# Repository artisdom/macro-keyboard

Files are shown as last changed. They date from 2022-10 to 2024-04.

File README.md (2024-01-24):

# Macro Keyboard

A Macro keyboard built on ESP32-S3.    

## Features

- Layouts: QMK style
- Macros: fakes multiple key presses on a single key.
- Deep sleep
- Battery level reports
- HID over USB or BLE.
- Support for multiple BLE hosts and specific key layout to switch between them.
- LED backlight with brightness control + effects for BLE actions

## Requirements

### Firmware

Using esp-idf (master branch)

### Hardware

Using Kicad v6.0

## Build

See the esp-idf [instructions](https://docs.espressif.com/projects/esp-idf/en/latest/esp32s3/get-started/index.html) on getting started.

To build:

```shell
idf.py build
```

To flash:

```shell
idf.py flash [-p port_name]
```

To get a console:

```shell
idf.py monitor [-p port_name]
```

### Keyboard Configuration

Each keyboard is defined in it's own subdirectory in the [keyboards](./firmware/keyboards) directory.
This keyboards directory is actually registered as a esp-idf component and will be built as a library and then linked with the [main](./firmware/main) component.

To choose which keyboard to compile for:

```shell
idf.py menuconfig
```
then `Keyboard Configuration` > `Keyboard to build`: Enter the name of the subdirectory for your keyboard.

## Todo

- Cleanup BLE files.
- Create an HID level to create packets to be routed to BLE or USB later on (waiting on esp to finish their esp_hid component).
- QMK features:
	- Make keymap fully compatible with QMK (maybe use the [QMK configurator](https://github.com/qmk/qmk_configurator) or the web api to compile keymaps).
	- Support for more Layer modifiers (one-shot, tap, etc...).
    - Better VIA compatibility (even thought it's a custom fork).
- Better NVS stuff (layouts, configs, ...etc).
- Better Battery reports (when init ble connection use read level).
- Low Battery management: indicator + shutdown.
- Battery optimisations: reduce polling rate when on battery + light sleep + power profiling for leakage currents.
- Clean up HID descriptors to make them common between USB and BLE stacks.
- Better USB deinit (waiting on TinyUSB implementation).
- USB CDC and HID device in parallel to get log outputs in serial port.
- MIDI device?
- Mutiple BLE hosts in parallel? + BLE 5 features?
- If design is kept as BLE only, shift implementation to NimBLE stack (not Bluedroid).
- SPI RAM usage? disabled for now because it was making boot time far too long.

## Issues

- Potential issue when switching BLE host: the hid report array is not propably reset.  
Should not be an issue as BLE host changes are supposed to happen without other keys being pressed.
- BLE local name needs to be less than 15 characters. Otherwise macOS will not show it in the discovery menu.

## License

Firmware and Software: MIT

Hardware: CERN-OHL-W v2

## Docs / Referencs

- ESP-IDF [Guide](https://docs.espressif.com/projects/esp-idf/en/v4.4.2/esp32s3/index.html).
- ESP32-S3 [Datasheet](https://www.espressif.com/sites/default/files/documentation/esp32-s3_datasheet_en.pdf).
- ESP32-S3 [Technical Reference Manual](https://www.espressif.com/sites/default/files/documentation/esp32-s3_technical_reference_manual_en.pdf).
- [TinyS3](https://esp32s3.com/index.html#home) board.
- [Blog](http://blog.komar.be/how-to-make-a-keyboard-the-matrix/) on matrix keyboard design. 
- QMK [keymaps](https://docs.qmk.fm/#/keymap?id=keymap-and-layers) and [layers](https://docs.qmk.fm/#/feature_layers) documentation.
- USB HID [usage tables](https://www.usb.org/sites/default/files/hut1_4.pdf)

### Inspirations

- [QMK](https://github.com/qmk/qmk_firmware/) for AVR devices.
- [MK32](https://github.com/Galzai/MK32) a QMK style firmware for ESP32 devices.

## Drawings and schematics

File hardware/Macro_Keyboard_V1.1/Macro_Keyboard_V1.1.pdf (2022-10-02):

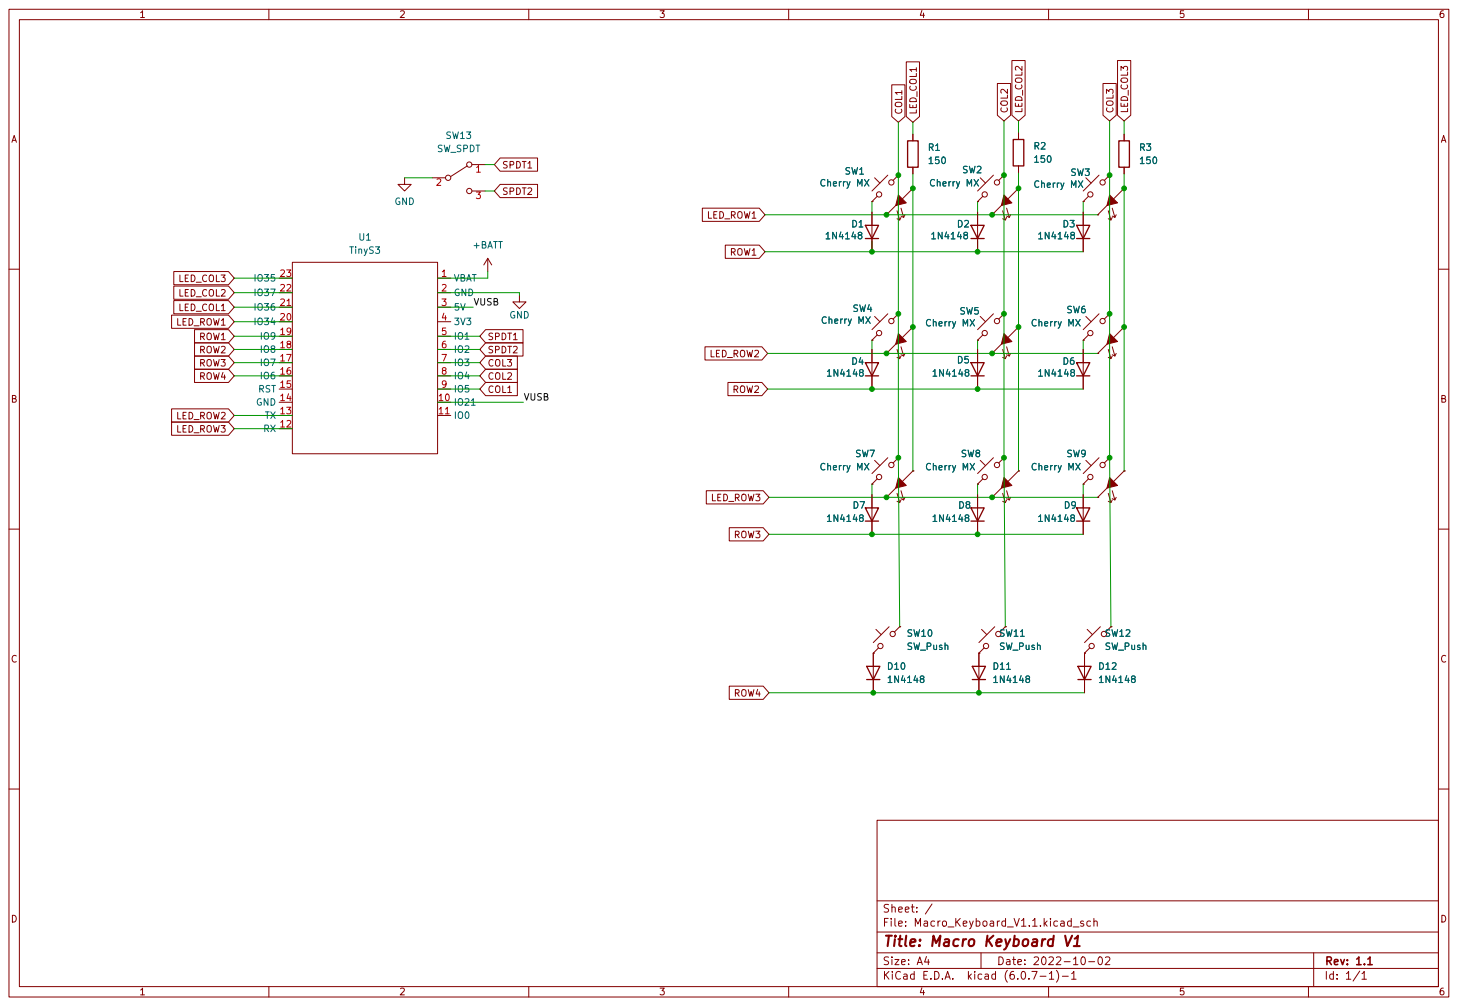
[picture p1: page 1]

File: Macro_Keyboard_V1.1.kicad_sch Sheet: /
Id: 1/1 Title: Macro Keyboard V1

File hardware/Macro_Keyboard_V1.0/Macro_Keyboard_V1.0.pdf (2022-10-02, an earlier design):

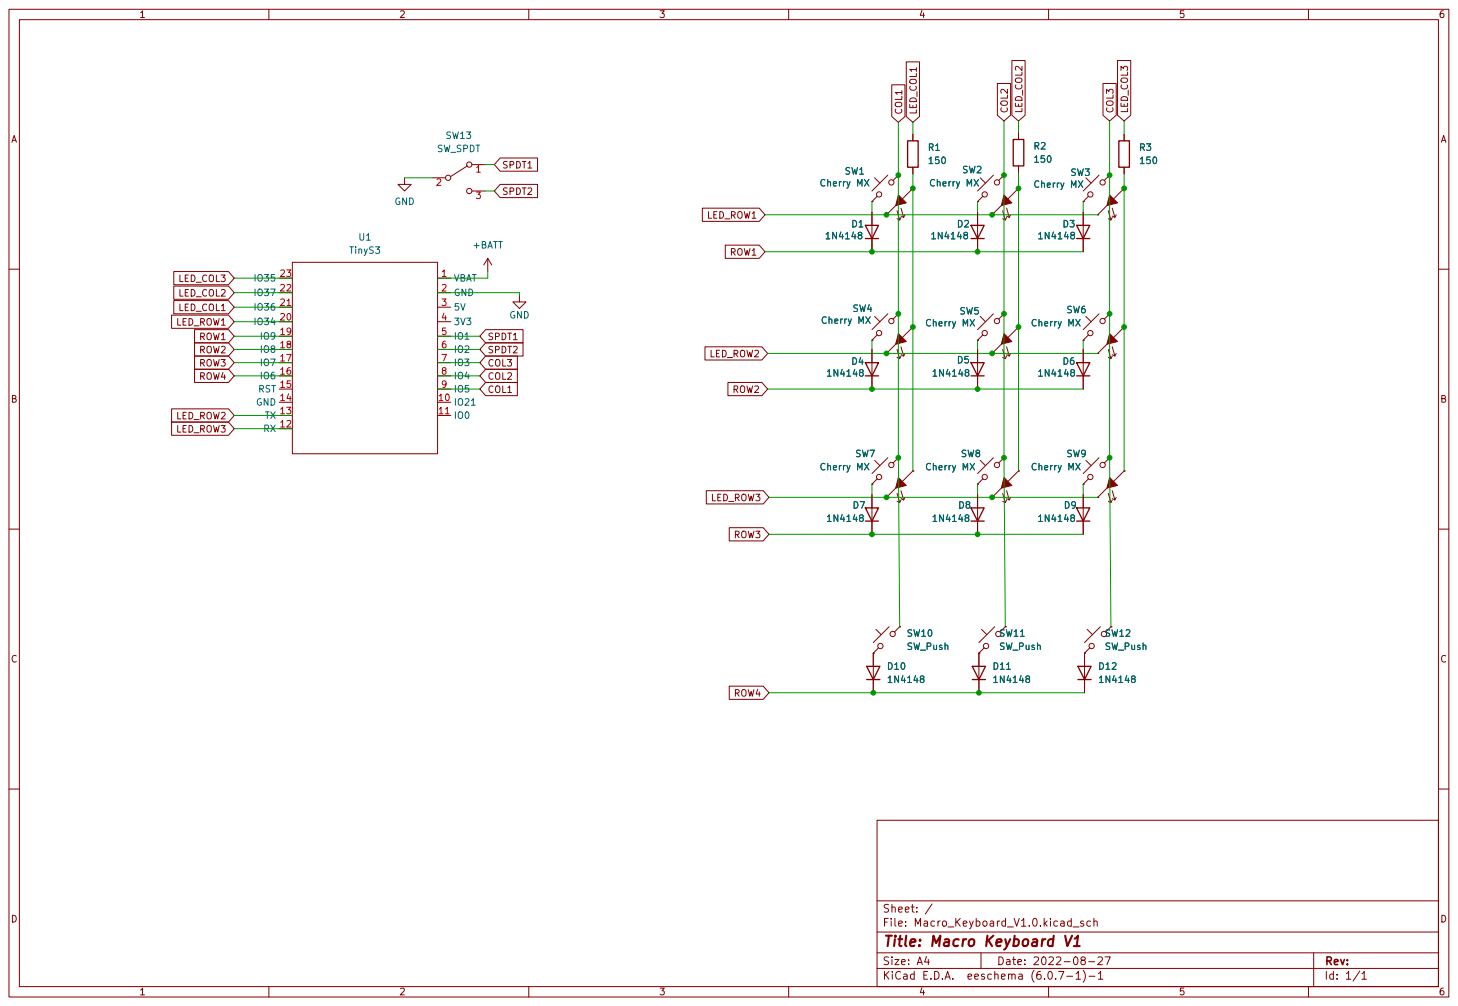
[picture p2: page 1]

File: Macro_Keyboard_V1.0.kicad_sch Sheet: /
Id: 1/1 Title: Macro Keyboard V1

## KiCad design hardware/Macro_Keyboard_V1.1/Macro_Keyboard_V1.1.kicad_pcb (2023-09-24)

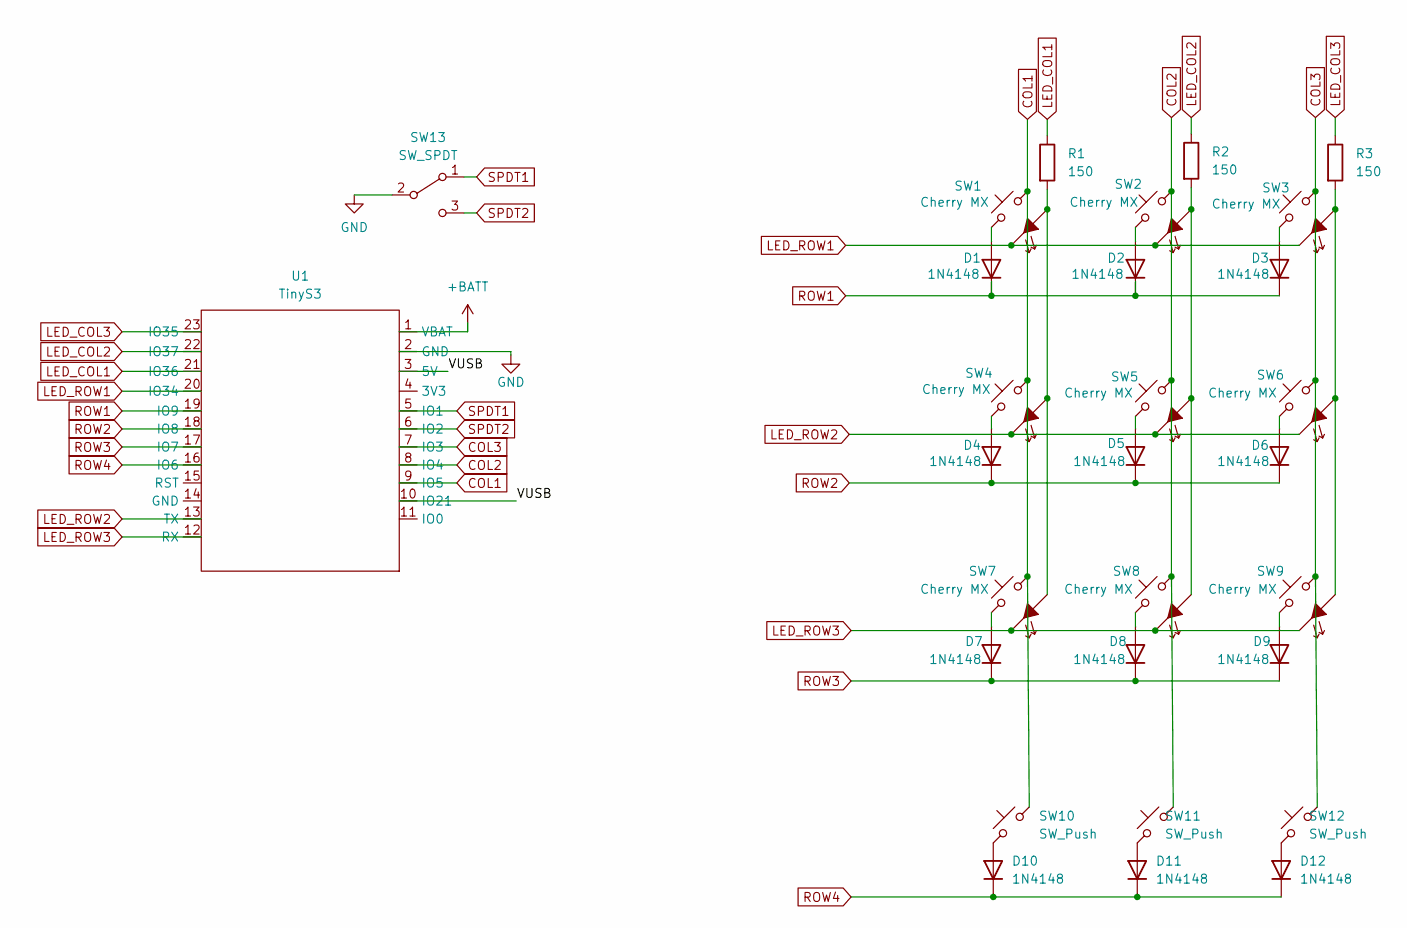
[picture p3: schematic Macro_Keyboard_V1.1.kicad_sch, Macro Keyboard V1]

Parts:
D1, D2, D3, D4, D5, D6, D7, D8, D9, D10, D11, D12: 1N4148; D_SOD-123
R1, R2, R3: 150; R_1206_3216Metric_Pad1.30x1.75mm_HandSolder
SW1, SW2, SW3, SW4, SW5, SW6, SW7, SW8, SW9: Cherry MX; CherryMX_1.00u_LED
SW10, SW11, SW12: SW_Push; SW_PUSH_6mm_H7.3mm
SW13: SW_SPDT; SK12D07VG4
U1: TinyS3

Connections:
+BATT: U1.1 (VBAT); also elsewhere on the board
/VUSB: U1.3 (5V), U1.10 (IO21)
COL1: SW1.1, SW4.1, SW7.1, SW10.2, U1.9 (IO5)
COL2: SW2.1, SW5.1, SW8.1, SW11.2, U1.8 (IO4)
COL3: SW3.1, SW6.1, SW9.1, SW12.2, U1.7 (IO3)
GND: SW13.2 (B), U1.2 (GND); also elsewhere on the board
LED_COL1: R1.1, U1.21 (IO36)
LED_COL2: R2.1, U1.22 (IO37)
LED_COL3: R3.1, U1.23 (IO35)
LED_ROW1: SW1.4, SW2.4, SW3.4, U1.20 (IO34)
LED_ROW2: SW4.4, SW5.4, SW6.4, U1.13 (TX)
LED_ROW3: SW7.4, SW8.4, SW9.4, U1.12 (RX)
unnamed: D1.2 (A), SW1.2
unnamed: D2.2 (A), SW2.2
unnamed: D3.2 (A), SW3.2
unnamed: D4.2 (A), SW4.2
unnamed: D5.2 (A), SW5.2
unnamed: D6.2 (A), SW6.2
unnamed: D7.2 (A), SW7.2
unnamed: D8.2 (A), SW8.2
unnamed: D9.2 (A), SW9.2
unnamed: D10.2 (A), SW10.1
unnamed: D11.2 (A), SW11.1
unnamed: D12.2 (A), SW12.1
unnamed: R1.2, SW1.3, SW4.3, SW7.3
unnamed: R2.2, SW2.3, SW5.3, SW8.3
unnamed: R3.2, SW3.3, SW6.3, SW9.3
ROW1: D1.1 (K), D2.1 (K), D3.1 (K), U1.19 (IO9)
ROW2: D4.1 (K), D5.1 (K), D6.1 (K), U1.18 (IO8)
ROW3: D7.1 (K), D8.1 (K), D9.1 (K), U1.17 (IO7)
ROW4: D10.1 (K), D11.1 (K), D12.1 (K), U1.16 (IO6)
SPDT1: SW13.1 (A), U1.5 (IO1)
SPDT2: SW13.3 (C), U1.6 (IO2)

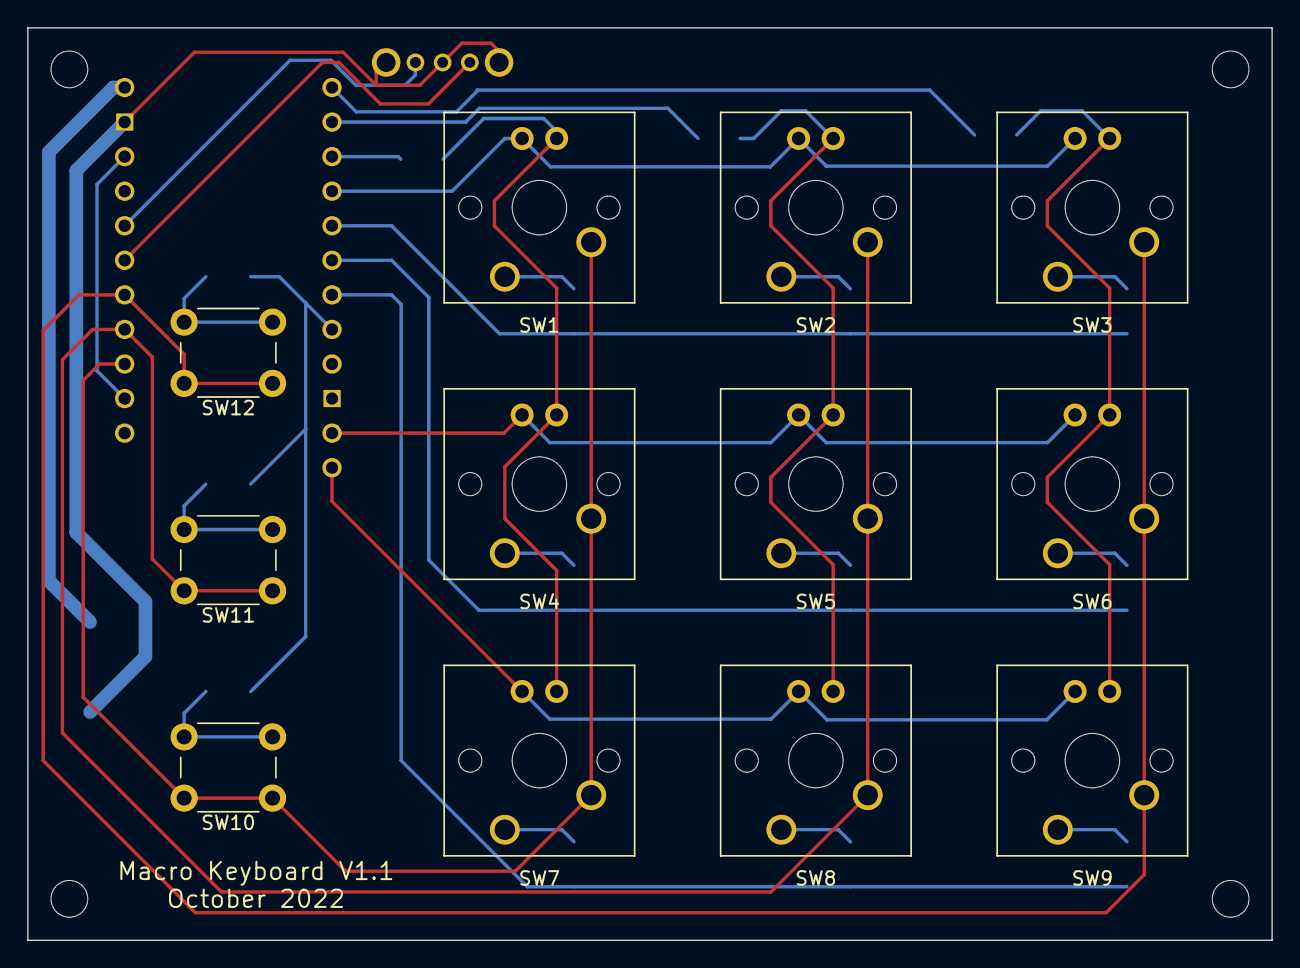
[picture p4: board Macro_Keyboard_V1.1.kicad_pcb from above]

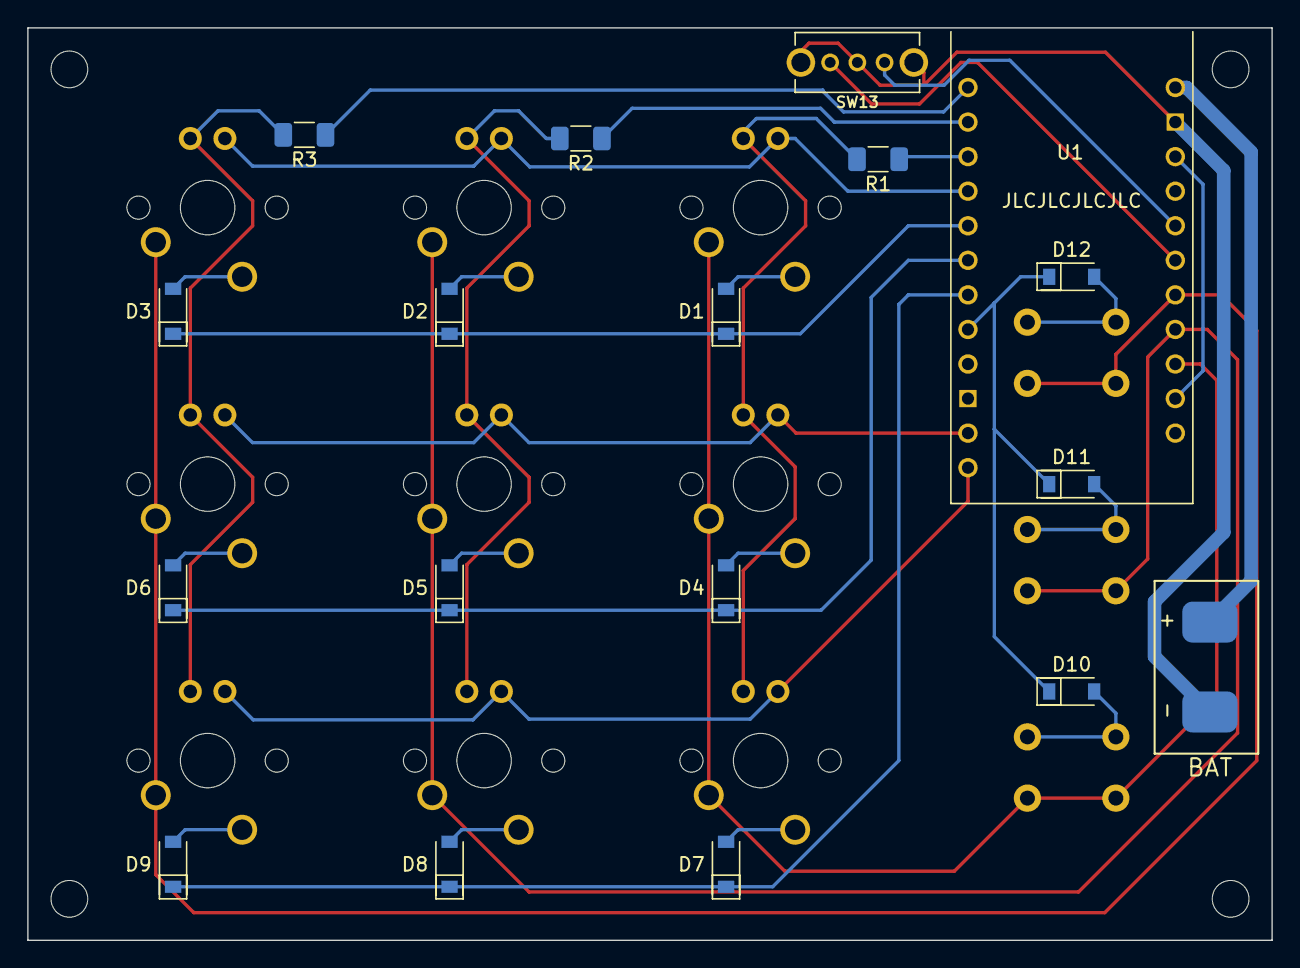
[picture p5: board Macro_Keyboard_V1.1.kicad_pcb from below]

Board: 2 copper layers, 91.4 x 67.1 mm, 31 parts (19 on the bottom side), 33 nets.

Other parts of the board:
+: SolderWirePad_1x01_SMD_3x4mm
-: SolderWirePad_1x01_SMD_3x4mm

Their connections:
+BATT: +.1; also elsewhere on the board
GND: -.1; also elsewhere on the board

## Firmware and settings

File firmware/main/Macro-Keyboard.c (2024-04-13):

#define LOG_LOCAL_LEVEL     ESP_LOG_DEBUG

#include <string.h>
#include "freertos/FreeRTOS.h"
#include "freertos/task.h"
#include "freertos/queue.h"
#include "esp_event.h"
#include "esp_sleep.h"
#include "esp_timer.h"
#include "esp_log.h"
#include "esp_system.h"
#include "driver/uart.h"
#include "driver/gpio.h"

#include "matrix.h"
#include "keyboard.h"
#include "memory.h"
#include "leds.h"
#include "events.h"
#include "toggle_switch.h"
#include "battery.h"
#include "ble.h"
#include "usb.h"


/* --------- Global Variables --------- */
QueueHandle_t event_q;
QueueHandle_t media_q;


/* --------- Local Defines --------- */
#define USEC_TO_SEC 1000000
#define SEC_TO_MIN 60

#define DEEP_SLEEP_TASK_RATE (5000) //in ms
#define BATTERY_TASK_RATE (DEEP_SLEEP_TIMEOUT * 1000 / 2)  //in ms


/* --------- Local Variables --------- */
static const char *TAG = "main";

static bool DEEP_SLEEP = true;

static uint8_t mode = TOGGLE_BLE;
static bool usb_connected;


/* --------- Local Functons --------- */
static void sleep(bool rtc_keyboard, bool rtc_toggle_switch, bool rtc_usb, bool rtc_usb_direction);
static void restart(restart_type_t type);


void keyboard_task(void *parameters) {

    uint8_t past_report[HID_REPORT_LEN] = {0};
    uint8_t *current_report;

    ESP_LOGI(TAG, "Starting keyboard task");

    while(1) {
        current_report = keyboard__check_state();

        // only send report if it changed
        if (memcmp(past_report, current_report, sizeof(past_report)) != 0) {
            DEEP_SLEEP = false;

            memcpy(past_report, current_report, sizeof(past_report));

            ESP_LOGD(TAG, "HID report:  0x%x,0x%x,  0x%x,0x%x,0x%x,0x%x,0x%x,0x%x",
                current_report[0], current_report[1], current_report[2], current_report[3],
                current_report[4], current_report[5], current_report[6], current_report[7]);

            if (BLE_ENABLED && (mode == TOGGLE_BLE)) {
                xQueueSend(ble_keyboard_q, (void *) current_report, (TickType_t) 0);
            }
            if (USB_ENABLED && (mode == TOGGLE_USB)) {
                xQueueSend(usb_keyboard_q, (void *) current_report, (TickType_t) 0);
            }

        }

        if (usb_connected == true) {
            vTaskDelay(KEYBOARD_RATE / portTICK_PERIOD_MS);
        }
        else {
            vTaskDelay(KEYBOARD_BLE_RATE / portTICK_PERIOD_MS);
        }
    }
    vTaskDelete(NULL);
    
}


void media_task(void *pvParameters) {

    uint8_t report[HID_CC_REPORT_LEN];
    uint8_t past_report[HID_CC_REPORT_LEN];

    ESP_LOGI(TAG, "Starting media task");

    while(1) {

        if (xQueueReceive(media_q, &report, (TickType_t) 100)) {
            // only send report if it changed
            if(memcmp(past_report, report, sizeof(past_report)) != 0) {
                DEEP_SLEEP = false;
                memcpy(past_report, report, sizeof(past_report));

                ESP_LOGD(TAG, "HID CC report:  %d,%d", report[0], report[1]);

                if (BLE_ENABLED && (mode == TOGGLE_BLE)) {
                    xQueueSend(ble_media_q, (void *) report, (TickType_t) 0);
                }
                if (USB_ENABLED && (mode == TOGGLE_USB)) {
                    xQueueSend(usb_media_q, (void *) report, (TickType_t) 0);
                }

            }    
        }

        if (usb_connected == true) {
            vTaskDelay(KEYBOARD_RATE / portTICK_PERIOD_MS);
        }
        else {
            vTaskDelay(KEYBOARD_BLE_RATE / portTICK_PERIOD_MS);
        }
    }
    vTaskDelete(NULL);

}


void battery_task(void *pvParameters) {

    ESP_LOGI(TAG, "Starting battery task");

    while(1) {
        uint32_t battery_level = battery__get_level();

        if (battery__is_charging()) {
            // if charging, disable DEEP_SLEEP
            DEEP_SLEEP = false;
        }

        if (BLE_ENABLED && (mode == TOGGLE_BLE)) {
            xQueueSend(ble_battery_q, &battery_level, (TickType_t) 0);
        }

        vTaskDelay(BATTERY_TASK_RATE / portTICK_PERIOD_MS);
    }

}


void deep_sleep_task(void *pvParameters) {
    uint64_t initial_time = esp_timer_get_time(); // time in micro-seconds
    uint64_t current_time_passed = 0;

    ESP_LOGI(TAG, "Starting deep sleep task");

    while (1) {
        current_time_passed = (esp_timer_get_time() - initial_time);

        if (DEEP_SLEEP == false) {
            current_time_passed = 0;
            initial_time = esp_timer_get_time();
            DEEP_SLEEP = true;
        }

        if (((double)current_time_passed/USEC_TO_SEC) >= (double)(DEEP_SLEEP_TIMEOUT)) {
            if (DEEP_SLEEP == true) {
                ESP_LOGW(TAG, "Deep sleep triggered");

                // deinits
                if (BLE_ENABLED && (mode == TOGGLE_BLE) && (ble__deinit() != ESP_OK)) {
                    ESP_LOGE(TAG, "Unable to go to sleep!");
                    DEEP_SLEEP = false;
                    continue;                    
                }
                if (USB_ENABLED && (mode == TOGGLE_USB) && (usb__deinit() != ESP_OK)) {
                    ESP_LOGE(TAG, "Unable to go to sleep!");
                    DEEP_SLEEP = false;
                    continue;                    
                }

                sleep(true, false, false, 0);
            }
            if (DEEP_SLEEP == false) {
                current_time_passed = 0;
                initial_time = esp_timer_get_time();
                DEEP_SLEEP = true;
            }
        }
        vTaskDelay(DEEP_SLEEP_TASK_RATE / portTICK_PERIOD_MS);
    }
    vTaskDelete(NULL);

}


void event_handler_task(void *parameters) {

    bt_event_t bt_event;

    ESP_LOGI(TAG, "Starting event handler task");

    if (event_q == NULL) {
        ESP_LOGW(TAG, "event queue not initialised, resetting...");
        xQueueReset(event_q);
    }

    while(1) {
        event_t event;
        event_t new_event;
        memset(&event, 0x00, sizeof(event_t));

        if(xQueueReceive(event_q, &event, portMAX_DELAY)) {
            
            switch(event.type) {
                case EVENT_KB_CHANGE_BT_HOST: {
                    bt_event.type = BT_EVENT_CHANGE_HOST;
                    bt_event.host_id = event.data;

                    if (BLE_ENABLED && (mode == TOGGLE_BLE)) {
                        ESP_LOGI(TAG, "Changing BLE device to %d", event.data);
                        xQueueSend(ble_event_q, &bt_event, (TickType_t) 0);
                    }
                    break;
                }
                case EVENT_KB_RESET_BT_HOST: {
                    bt_event.type = BT_EVENT_RESET_HOST;
                    bt_event.host_id = event.data;

                    if (BLE_ENABLED && (mode == TOGGLE_BLE)) {
                        ESP_LOGI(TAG, "Resetting BLE device at %d", event.data);
                        xQueueSend(ble_event_q, &bt_event, (TickType_t) 0);
                    }
                    break;
                }
                case EVENT_TOGGLE_SWITCH: {
                    if ((event.data == TOGGLE_BLE)) {
                        // ESP_LOGW(TAG, "event toggle ble");
                        if (USB_ENABLED) {
                            usb__deinit();
                        }
                        if (BLE_ENABLED) {
                            ESP_LOGI(TAG, "Toggle BLE");
                            if (LED_ENABLED && LED_EFFECTS_ENABLED) {
                                new_event.type = EVENT_BT_LEDS_EFFECT_TOGGLE,
                                new_event.data = true;
                                xQueueSend(leds_q, &new_event, (TickType_t) 0);
                            }
                            mode = event.data;
                            ble__init();
                        }
                    }
                    else if ((event.data == TOGGLE_USB)) {
                        // ESP_LOGW(TAG, "event toggle usb");
                        usb_connected = usb__is_connected();
                        if (BLE_ENABLED) {
                            if (LED_ENABLED && LED_EFFECTS_ENABLED) {
                                new_event.type = EVENT_BT_LEDS_EFFECT_TOGGLE,
                                new_event.data = false;
                                xQueueSend(leds_q, &new_event, (TickType_t) 0);
                            }
                            ble__deinit();
                        }
                        if (USB_ENABLED) {
                            if (usb_connected) {
                                ESP_LOGI(TAG, "Toggle USB");
                                mode = event.data;
                                usb__init();
                            }
                            else {
                                sleep(false, true, true, !usb_connected);
                            }
                        }
                        else {
                            sleep(false, true, false, 0);
                        }
                    }
                    else {
                        ESP_LOGW(TAG, "Unknown toggle event type %d", event.data);
                    }
                    break;
                }
                case EVENT_KB_LEDS: {
                    if (LED_ENABLED) {
                        switch (event.data) {
                            case LEDS_ON:
                                ESP_LOGD(TAG, "Leds on");
                                leds__enable_backlight(true);
                                break;
                            case LEDS_OFF:
                                ESP_LOGD(TAG, "Leds off");
                                leds__enable_backlight(false);
                                break;
                            case LEDS_TOGGLE:
                                ESP_LOGD(TAG, "Leds toggle");
                                leds__toggle_backlight();
                                break;
                            case LEDS_INCREMENT:
                                ESP_LOGD(TAG, "Leds increase brightness");
                                leds__increase_brightness();
                                break;
                            case LEDS_DECREMENT:
                                ESP_LOGD(TAG, "Leds decrease brightness");
                                leds__decrease_brightness();
                                break;
                            default:
                                ESP_LOGE(TAG, "Unrecognised KB_LEDS event data %d", event.data);
                                break;
                        }
                    }
                    break;
                }
                case EVENT_BT_ADV:
                case EVENT_BT_ADV_ALL:
                case EVENT_BT_CONNECTED:
                case EVENT_LAYERS_CHANGED: {
                    if (LED_ENABLED && LED_BT_EFFECTS_ENABLED) {
                        ESP_LOGI(TAG, "Leds FX event, host: %d", event.data);
                        xQueueSend(leds_q, &event, (TickType_t) 0);
                    }
                    break;
                }
                case EVENT_USB_PORT: {
                    vTaskDelay(1 / portTICK_PERIOD_MS); // delay to wait for voltage to stabilise on pin
                    usb_connected = usb__is_connected();
                    if (usb_connected == true) {
                        ESP_LOGI(TAG, "USB Connected");
                    }
                    else {
                        ESP_LOGI(TAG, "USB Disconnected");
                        if (mode == TOGGLE_USB) {
                            sleep(false, true, true, 1);
                        }

                    }
                    break;
                }
                case EVENT_RESTART: {
                    if (event.data > 0) {
                        restart((restart_type_t) event.data);
                    }
                    else {
                        ESP_LOGE(TAG, "Unrecognised EVENT_RESTART event data %d", event.data);
                    }
                    break;
                }
                default:
                    ESP_LOGW(TAG, "Unhandled event type");
                    break;
            }
        }
    }
    vTaskDelete(NULL);
}


static void logging_init() {

    // ESP-IDF modules
    esp_log_level_set("*", ESP_LOG_INFO);
    esp_log_level_set("ledc", ESP_LOG_INFO);
    esp_log_level_set("TinyUSB", ESP_LOG_INFO);

    // local modules
    esp_log_level_set("main", ESP_LOG_DEBUG);
    esp_log_level_set("matrix", ESP_LOG_INFO);
    esp_log_level_set("keyboard", ESP_LOG_INFO);
    esp_log_level_set("layers", ESP_LOG_INFO);
    esp_log_level_set("dynamic_keymap", ESP_LOG_INFO);
    esp_log_level_set("memory", ESP_LOG_INFO);
    esp_log_level_set("leds", ESP_LOG_INFO);
    esp_log_level_set("toggle_switch", ESP_LOG_INFO);
    esp_log_level_set("battery", ESP_LOG_INFO);
    esp_log_level_set("usb", ESP_LOG_INFO);
    esp_log_level_set("via", ESP_LOG_INFO);
    esp_log_level_set("ble", ESP_LOG_INFO);
    esp_log_level_set("hid_le_prf", ESP_LOG_INFO);

}


void app_main(void) {

    // run first to disable interrupts
    matrix__rtc_deinit();
    toggle_switch__rtc_deinit();
    usb__rtc_deinit();

    logging_init();
    ESP_LOGI(TAG, "Hello");

    memory__init();

    esp_sleep_wakeup_cause_t wakeup = esp_sleep_get_wakeup_cause();
    if (wakeup == ESP_SLEEP_WAKEUP_EXT1) {
        ESP_LOGI(TAG, "Wakeup from deep-sleep");
        uint64_t bit_mask = esp_sleep_get_ext1_wakeup_status();
        ESP_LOGD(TAG, "wakeup gpio bit mask: 0x%llx", bit_mask);
        memory__set_sleep_counter();
    }
    else if (wakeup == ESP_SLEEP_WAKEUP_EXT0) {
         ESP_LOGI(TAG, "Wakeup from USB bus GPIO");
         if (memory__get_sleep_status() == true) {
            if (USB_ENABLED) {
                sleep(false, true, true, 1);
            }
            else {
                sleep(false, true, false, 0);
            }
         }
    }
    else {
        ESP_LOGI(TAG, "Wakeup from normal boot");
        ESP_LOGD(TAG, "wakeup cause: %d", esp_sleep_get_wakeup_cause());
        memory__set_restart_counter();
    }

    event_q = xQueueCreate(32, sizeof(event_t));
    media_q = xQueueCreate(32, HID_CC_REPORT_LEN * sizeof(uint8_t));

    matrix__init();
    keyboard__init();

    if (TOGGLE_SWITCH_ENABLED) {
        toggle_switch__init();
        mode = toggle_switch__get_state();
    }
    if (BLE_ENABLED && (mode == TOGGLE_BLE)) {
        ble__init();
    }
    if (USB_ENABLED && (mode == TOGGLE_USB)) {
        usb__init();
    }

    if (USB_DETECT_ENABLED) {
        usb__init_detection();
        usb_connected = usb__is_connected();
    }

    if (LED_ENABLED) {
        leds__init();
    }

    if (BATTERY_ENABLED) {
        battery__init();
        xTaskCreatePinnedToCore(battery_task, "battery task", BATTERY_TASK_STACK, NULL, BATTERY_TASK_PRIORITY, NULL, 1);
    }

    xTaskCreatePinnedToCore(keyboard_task, "keyboard task", KEYBOARD_TASK_STACK, NULL, KEYBOARD_TASK_PRIORITY, NULL, 1);
    xTaskCreatePinnedToCore(media_task, "media task", MEDIA_TASK_STACK, NULL, MEDIA_TASK_PRIORITY, NULL, 1);
    xTaskCreatePinnedToCore(event_handler_task, "event handler task", EVENT_HANDLER_TASK_STACK, NULL, EVENT_HANDLER_TASK_PRIORITY, NULL, 1);

    if (DEEP_SLEEP_ENABLED) {
        xTaskCreatePinnedToCore(deep_sleep_task, "deep sleep task", DEEP_SLEEP_TASK_STACK, NULL, DEEP_SLEEP_TASK_PRIORITY, NULL, 1);
    }

}



static void sleep(bool rtc_keyboard, bool rtc_toggle_switch, bool rtc_usb, bool rtc_usb_direction) {

    ESP_LOGD(TAG, "Setting up for sleep...");
    if (rtc_keyboard) {
        matrix__rtc_setup();
    }
    if (rtc_toggle_switch && TOGGLE_SWITCH_ENABLED) {
        toggle_switch__rtc_setup();
    }
    if (rtc_usb && USB_DETECT_ENABLED) {
        memory__set_sleep_status(!rtc_usb_direction);
        usb__rtc_setup(rtc_usb_direction);
    }

    esp_sleep_pd_config(ESP_PD_DOMAIN_RTC_PERIPH, ESP_PD_OPTION_ON);
    ESP_LOGW(TAG, "Going to sleep................!");
    esp_deep_sleep_start();

}


static void restart(restart_type_t type) {

    ESP_LOGD(TAG, "Setting up for restart...");

    usb__set_restart_mode(type);
    if (type >= RESTART_BOOTLOADER) {
        ESP_ERROR_CHECK(esp_register_shutdown_handler(usb__shutdown_handler));
        usb__switch_to_cdc_jtag();
    }
    if (type == RESTART_USB) {
        usb__switch_to_cdc_jtag();
        ESP_LOGW(TAG, "Skipping restart");
        return;
    }

    ESP_LOGW(TAG, "Restarting................!");
    esp_restart();
}

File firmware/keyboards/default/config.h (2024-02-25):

#ifndef CONFIG_H
#define CONFIG_H

/* --------- Global configs --------- */
#define DEVICE_NAME               "Macro Keyboard" // max 15 chars for macOS
#define DEEP_SLEEP_ENABLED        (1)
#define DEEP_SLEEP_TIMEOUT        (3600) // in seconds 
#define TOGGLE_SWITCH_ENABLED     (1)
#define BATTERY_ENABLED           (1)
#define VIA_ENABLED               (1)


/* --------- Key matrix configs --------- */
#define MATRIX_ROWS               (4)
#define MATRIX_COLS               (3)

#define DEBOUNCE_TIME             (4)   // in ms
#define KEYBOARD_RATE             (1u)  // in ms
#define KEYBOARD_BLE_RATE         (10u) // in ms


/* --------- Keymap configs --------- */
#define DEFAULT_LAYER             (0)
#define MAX_LAYER                 (32)

#define MACRO_LEN                 (3)
#define MAX_MACRO                 (16) // locked by VIA's crappy macro system
#define ONESHOT_TIMEOUT           (3)  // in seconds


/* --------- BLE configs --------- */
#define BLE_DEVICE_NAME           DEVICE_NAME
#define BLE_ENABLED               (1)
#define HID_REPORT_LEN            (8)
#define HID_CC_REPORT_LEN         (2)
#define BLE_NUM_HOSTS             (3)


/* --------- USB configs --------- */
#define USB_ENABLED               (1)
#define USB_DETECT_ENABLED        (1)   // detect cable plugged in
#define USB_MANUFACTURER_NAME     "Patopest"
#define USB_DEVICE_NAME           DEVICE_NAME
#define USB_HID_NAME              DEVICE_NAME " HID"
#define USB_CDC_NAME              DEVICE_NAME " CDC"
#define USB_MIDI_NAME             DEVICE_NAME " MIDI"


/* --------- Led matrix configs --------- */
#define LED_ENABLED               (1)
#define LED_EFFECTS_ENABLED       (1)
#define LED_BT_EFFECTS_ENABLED    (1)
#define LED_LAYER_EFFECTS_ENABLED (1)
#define LED_ROWS                  (3)
#define LED_COLS                  (3)



/* --------- FreeRTOS configs --------- */
#define KEYBOARD_TASK_STACK             (8192)
#define KEYBOARD_TASK_PRIORITY          (configMAX_PRIORITIES)
#define MEDIA_TASK_STACK                (8192)
#define MEDIA_TASK_PRIORITY             (configMAX_PRIORITIES)
#define BATTERY_TASK_STACK              (4096)
#define BATTERY_TASK_PRIORITY           (configMAX_PRIORITIES)
#define EVENT_HANDLER_TASK_STACK        (8192)
#define EVENT_HANDLER_TASK_PRIORITY     (configMAX_PRIORITIES)
#define DEEP_SLEEP_TASK_STACK           (4096)
#define DEEP_SLEEP_TASK_PRIORITY        (configMAX_PRIORITIES)
#define LEDS_TASK_STACK                 (4096)
#define LEDS_TASK_PRIORITY              (configMAX_PRIORITIES)

#define BLE_KEYBOARD_TASK_STACK         (2048)
#define BLE_KEYBOARD_TASK_PRIORITY      (configMAX_PRIORITIES)
#define BLE_MEDIA_TASK_STACK            (2048)
#define BLE_MEDIA_TASK_PRIORITY         (configMAX_PRIORITIES)
#define BLE_BATTERY_TASK_STACK          (2048)
#define BLE_BATTERY_TASK_PRIORITY       (configMAX_PRIORITIES)
#define BLE_EVENT_TASK_STACK            (4096)
#define BLE_EVENT_TASK_PRIORITY         (configMAX_PRIORITIES)

#define USB_TINYUSB_TASK_STACK          (4096)
#define USB_TINYUSB_TASK_PRIORITY       (5)
#define USB_KEYBOARD_TASK_STACK         (4096)
#define USB_KEYBOARD_TASK_PRIORITY      (configMAX_PRIORITIES)
#define USB_MEDIA_TASK_STACK            (2048)
#define USB_MEDIA_TASK_PRIORITY         (configMAX_PRIORITIES)


#endif

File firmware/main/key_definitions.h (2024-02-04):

#ifndef KEY_DEFINITIONS_H
#define KEY_DEFINITIONS_H

/*
File is generated using the keycodes definition json or toml files
  Generated on: 04-02-2024 13:27:01
  Version: v1.11
  Git commit (keycodes repository): 559666e
*/

enum keycode_ranges {
	QK_BASIC                       = 0x0000,
	QK_BASIC_MAX                   = 0x00FF,
	QK_MODS                        = 0x0100,
	QK_MODS_MAX                    = 0x1FFF,
	QK_CONSUMER                    = 0x2000,
	QK_CONSUMER_MAX                = 0x2FFF,
	QK_MACRO                       = 0x3000,
	QK_MACRO_MAX                   = 0x30FF,
	QK_TO                          = 0x5000,
	QK_TO_MAX                      = 0x50FF,
	QK_MOMENTARY                   = 0x5100,
	QK_MOMENTARY_MAX               = 0x51FF,
	QK_DEF_LAYER                   = 0x5200,
	QK_DEF_LAYER_MAX               = 0x52FF,
	QK_TOGGLE_LAYER                = 0x5300,
	QK_TOGGLE_LAYER_MAX            = 0x53FF,
	QK_ONE_SHOT_LAYER              = 0x5400,
	QK_ONE_SHOT_LAYER_MAX          = 0x54FF,
	QK_BT_HOST                     = 0x6000,
	QK_BT_HOST_MAX                 = 0x60FF,
	QK_BT_HOST_RESET               = 0x6100,
	QK_BT_HOST_RESET_MAX           = 0x61FF,
	QK_LIGHTING                    = 0x7000,
	QK_LIGHTING_MAX                = 0x70FF,
	QK_DEBUG                       = 0x7100,
	QK_DEBUG_MAX                   = 0x710F,
};

// Switch statement helpers
#define QK_BASIC_RANGE             QK_BASIC ... QK_BASIC_MAX
#define QK_MODS_RANGE              QK_MODS ... QK_MODS_MAX
#define QK_CONSUMER_RANGE          QK_CONSUMER ... QK_CONSUMER_MAX
#define QK_MACRO_RANGE             QK_MACRO ... QK_MACRO_MAX
#define QK_TO_RANGE                QK_TO ... QK_TO_MAX
#define QK_MOMENTARY_RANGE         QK_MOMENTARY ... QK_MOMENTARY_MAX
#define QK_DEF_LAYER_RANGE         QK_DEF_LAYER ... QK_DEF_LAYER_MAX
#define QK_TOGGLE_LAYER_RANGE      QK_TOGGLE_LAYER ... QK_TOGGLE_LAYER_MAX
#define QK_ONE_SHOT_LAYER_RANGE    QK_ONE_SHOT_LAYER ... QK_ONE_SHOT_LAYER_MAX
#define QK_BT_HOST_RANGE           QK_BT_HOST ... QK_BT_HOST_MAX
#define QK_BT_HOST_RESET_RANGE     QK_BT_HOST_RESET ... QK_BT_HOST_RESET_MAX
#define QK_LIGHTING_RANGE          QK_LIGHTING ... QK_LIGHTING_MAX
#define QK_DEBUG_RANGE             QK_DEBUG ... QK_DEBUG_MAX



enum keycodes {
	// Keycodes
	/* internal */
	KC_NO           = 0x0000,
	KC_TRANSPARENT  = 0x0001,
	/* basic */
	KC_A            = 0x0004,
	KC_B            = 0x0005,
	KC_C            = 0x0006,
	KC_D            = 0x0007,
	KC_E            = 0x0008,
	KC_F            = 0x0009,
	KC_G            = 0x000A,
	KC_H            = 0x000B,
	KC_I            = 0x000C,
	KC_J            = 0x000D,
	KC_K            = 0x000E,
	KC_L            = 0x000F,
	KC_M            = 0x0010,
	KC_N            = 0x0011,
	KC_O            = 0x0012,
	KC_P            = 0x0013,
	KC_Q            = 0x0014,
	KC_R            = 0x0015,
	KC_S            = 0x0016,
	KC_T            = 0x0017,
	KC_U            = 0x0018,
	KC_V            = 0x0019,
	KC_W            = 0x001A,
	KC_X            = 0x001B,
	KC_Y            = 0x001C,
	KC_Z            = 0x001D,
	KC_1            = 0x001E,
	KC_2            = 0x001F,
	KC_3            = 0x0020,
	KC_4            = 0x0021,
	KC_5            = 0x0022,
	KC_6            = 0x0023,
	KC_7            = 0x0024,
	KC_8            = 0x0025,
	KC_9            = 0x0026,
	KC_0            = 0x0027,
	KC_ENTER        = 0x0028,
	KC_ESCAPE       = 0x0029,
	KC_BACKSPACE    = 0x002A,
	KC_TAB          = 0x002B,
	KC_SPACE        = 0x002C,
	KC_MINUS        = 0x002D,
	KC_EQUAL        = 0x002E,
	KC_LEFT_BRACKET = 0x002F,
	KC_RIGHT_BRACKET = 0x0030,
	KC_BACKSLASH    = 0x0031,
	KC_NONUS_HASH   = 0x0032,
	KC_SEMICOLON    = 0x0033,
	KC_QUOTE        = 0x0034,
	KC_GRAVE        = 0x0035,
	KC_COMMA        = 0x0036,
	KC_DOT          = 0x0037,
	KC_SLASH        = 0x0038,
	KC_CAPS_LOCK    = 0x0039,
	KC_F1           = 0x003A,
	KC_F2           = 0x003B,
	KC_F3           = 0x003C,
	KC_F4           = 0x003D,
	KC_F5           = 0x003E,
	KC_F6           = 0x003F,
	KC_F7           = 0x0040,
	KC_F8           = 0x0041,
	KC_F9           = 0x0042,
	KC_F10          = 0x0043,
	KC_F11          = 0x0044,
	KC_F12          = 0x0045,
	KC_PRINT_SCREEN = 0x0046,
	KC_SCROLL_LOCK  = 0x0047,
	KC_PAUSE        = 0x0048,
	KC_INSERT       = 0x0049,
	KC_HOME         = 0x004A,
	KC_PAGE_UP      = 0x004B,
	KC_DELETE       = 0x004C,
	KC_END          = 0x004D,
	KC_PAGE_DOWN    = 0x004E,
	KC_RIGHT        = 0x004F,
	KC_LEFT         = 0x0050,
	KC_DOWN         = 0x0051,
	KC_UP           = 0x0052,
	KC_NUM_LOCK     = 0x0053,
	KC_KP_SLASH     = 0x0054,
	KC_KP_ASTERISK  = 0x0055,
	KC_KP_MINUS     = 0x0056,
	KC_KP_PLUS      = 0x0057,
	KC_KP_ENTER     = 0x0058,
	KC_KP_1         = 0x0059,
	KC_KP_2         = 0x005A,
	KC_KP_3         = 0x005B,
	KC_KP_4         = 0x005C,
	KC_KP_5         = 0x005D,
	KC_KP_6         = 0x005E,
	KC_KP_7         = 0x005F,
	KC_KP_8         = 0x0060,
	KC_KP_9         = 0x0061,
	KC_KP_0         = 0x0062,
	KC_KP_DOT       = 0x0063,
	KC_NONUS_BACKSLASH = 0x0064,
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

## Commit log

2022-08-21 Added support for multiple BLE hosts and switch between them
2022-08-23 Preliminary LED driver
2022-08-23 Added support for Esp32S3 chip with logging throught USB
2022-08-28 Updates to keyboard matrix to fit current HW design
2022-08-28 Update to LED matrix config to test for current HW design
2022-09-01 Added simple battery level reports
2022-09-01 Added usb voltage detection
2022-09-01 Added bluetooth host reset as a keycode
    [Macro-Keyboard.c, key_definitions.h]
2022-09-04 Migrated to esp-idf master branch
    For development of the HID over USB, will switch to a stable release or branch later
2022-09-07 Added Brightness control on backlight leds
    with special keycodes and events to handle it + each led matrix column uses a separate LEDC channel
2022-09-17 Finally got a tiny effect task for leds based on bluetooth events
2022-09-19 Modifications to run on V1 hardware
    Extended keymaps + fixed toggle switch events and added debounce in the ISR handler
    [Macro-Keyboard.c, config.h, matrix.c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]
2022-09-20 Fixed compilation warnings for new ADC driver
    [Macro-Keyboard.c, battery.c]
2022-09-22 Fixed led effect driver
    Added CIE1951 linear brightness curve
    [config.h, leds.c]
2022-09-30 Misc improvements to sleep behavious
    Added toggle switch RTC wakeup and better deinit of matrix RTC
2022-10-02 Finalised sleep behaviours
    Added USB cable detection, refactored sleep logic, refactored memory NVS interface
2022-10-02 Added Hardware v1.0
    Changed project layout to account for hardware directories
    [Macro_Keyboard_V1.0-B_Cu.gbl, Macro_Keyboard_V1.0-B_Mask.gbs, Macro_Keyboard_V1.0-B_Paste.gbp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]
2022-10-02 Added Hardware v1.1
    Added USB bus voltage to an RTC pin for USB wakeups + Better diode symbol
    [Macro_Keyboard_V1.1-B_Cu.gbl, Macro_Keyboard_V1.1-B_Mask.gbs, Macro_Keyboard_V1.1-B_Paste.gbp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]
2022-10-21 Fixed LED bluetooth effects on USB toggle
    [Macro-Keyboard.c, config.h, leds.c]
2022-10-24 Added on layer change led effects
2022-10-24 misc improvements and fixes
    Fixed momentary layer effects, Fixed media keys, Added console through USB CDC
    [key_definitions.h, usb.c]
2022-12-03 Misc tweaks
    BLE switching and task rate on battery management + uart redirection on boot
2022-12-05 Fixed led effects when changing
    [leds.c]
2023-09-24 Added 3d models for all components
    [Macro_Keyboard_V1.1.kicad_pcb, Macro_Keyboard_V1.1.kicad_sch]
2023-12-03 Finally able to reboot in bootloader download mode
    [Macro-Keyboard.c, usb.c]
2023-12-04 Fix for TinyUSB tud_hid_set_report_cb no being called on VIA packet reception
    [usb.c]
2024-02-25 Fixed battery level on BLE connection
    [Macro-Keyboard.c, config.h]
2024-04-13 Fixed BLE host led effects on boot
    [Macro-Keyboard.c, leds.c]
